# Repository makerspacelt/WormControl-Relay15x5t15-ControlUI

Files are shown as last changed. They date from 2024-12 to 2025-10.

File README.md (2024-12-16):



---
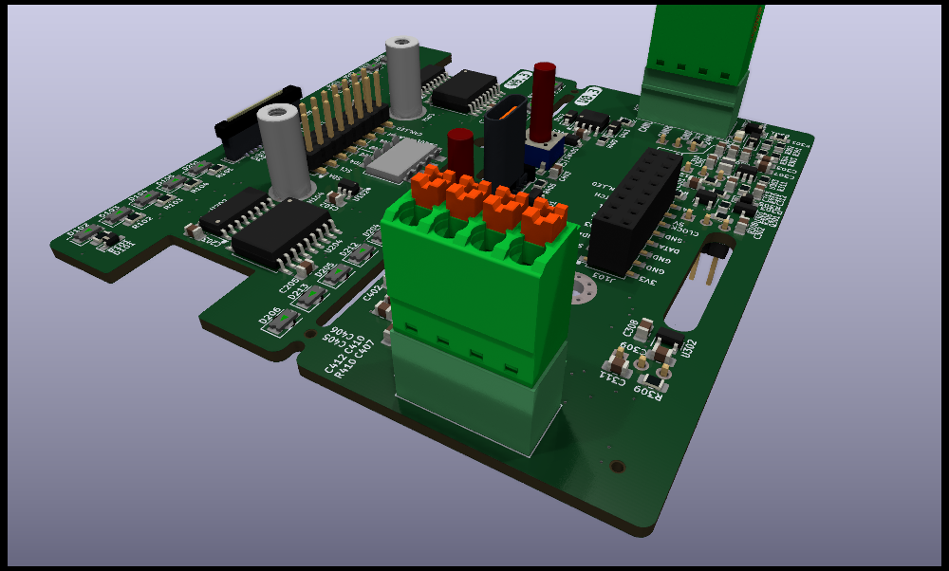
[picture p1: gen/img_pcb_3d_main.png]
PCB 3d main


WormControl Relay Control and User Interface boards

NOTE: This is only a prototype now, so things might not work and everything might change 

Basic target features:

* Compatibility with esphome and Home Assistant

Dev NOTE: before commit, run `./kibot.sh` to regenerate documentation, bom, gerbers and other assets.

* [schematics.pdf](gen/schematics.pdf)
* [pcb.pdf with dimensions](gen/pcb.pdf)
* [ibom.html](gen/single/ibom.html)

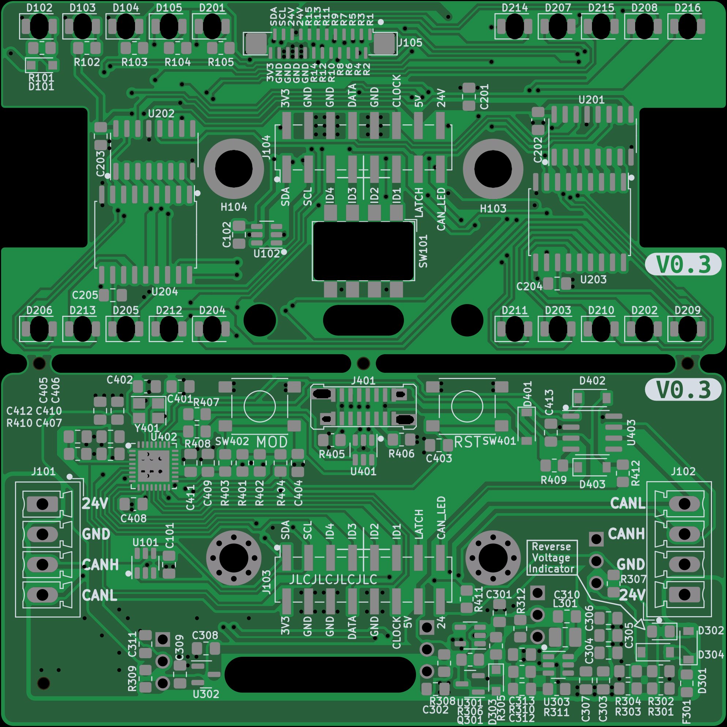
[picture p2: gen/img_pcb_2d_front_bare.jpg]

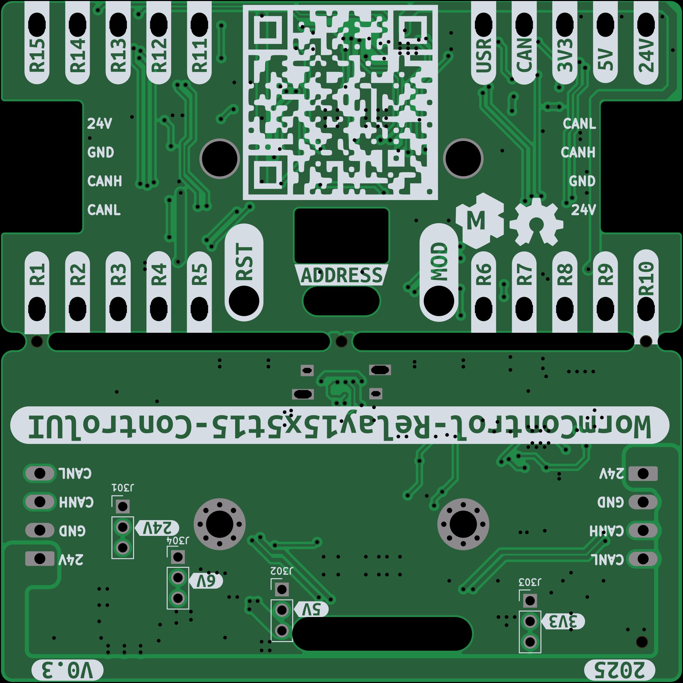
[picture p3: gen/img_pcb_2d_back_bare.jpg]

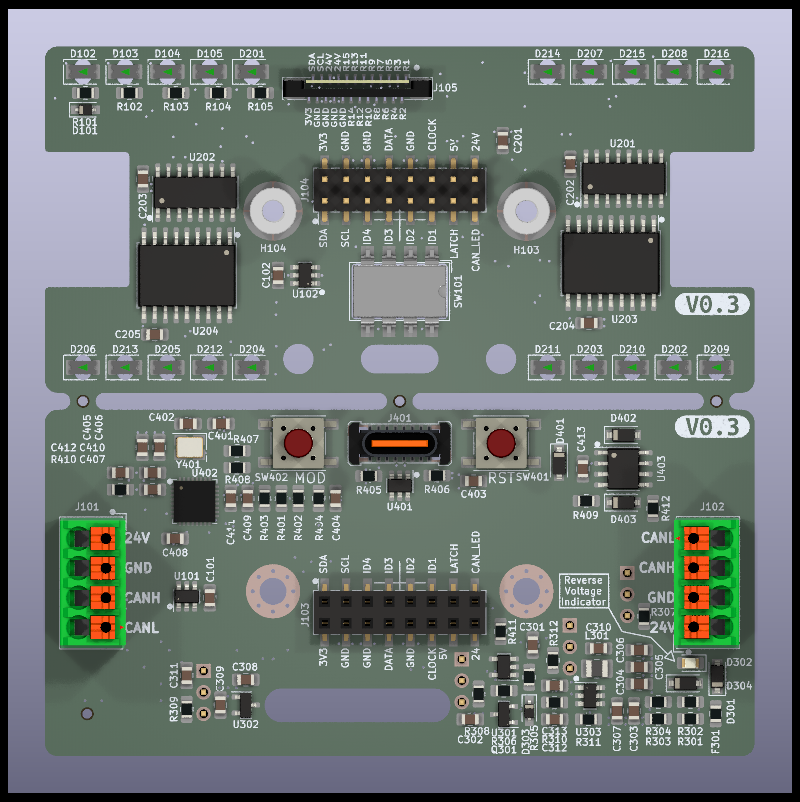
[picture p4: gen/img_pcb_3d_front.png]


---

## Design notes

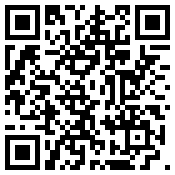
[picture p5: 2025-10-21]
gen/qr_link.png

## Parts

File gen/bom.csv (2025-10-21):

Row | Description | Part | References | Value | Footprint | Quantity Per PCB | Status | Datasheet | lcsc# | jlc-part-type | alt#
1 | Heatsink | Heatsink | BOM101,BOM102 | 1x4 screw plug |  | 2 |  | https://www.lcsc.com/datasheet/lcsc_datasheet_2309070925_DEGSON-15EDGKN-3-5-04P-14-00A-H_C7603442.pdf | C7603442 | E
2 | Unpolarized capacitor | C | C401,C402 | 10p | C_0805_2012Metric_Pad1.18x1.45mm_HandSolder | 2 |  | https://www.lcsc.com/datasheet/lcsc_datasheet_2304140030_Samsung-Electro-Mechanics-CL10C100JB8NNNC_C1634.pdf | C1634 | B
3 | Unpolarized capacitor | C | C312 | 100p | C_0805_2012Metric_Pad1.18x1.45mm_HandSolder | 1 |  | https://www.lcsc.com/datasheet/lcsc_datasheet_2304140030_Samsung-Electro-Mechanics-CL21C101JBANNNC_C1790.pdf | C1790 | B
4 | Unpolarized capacitor | C | C101,C102,C202,C203,C307,C310,C403,C404,C407,C408,C409,C410,C411,C412,C413 | 100n | C_0805_2012Metric_Pad1.18x1.45mm_HandSolder | 15 |  | https://www.lcsc.com/datasheet/lcsc_datasheet_2304140030_Samsung-Electro-Mechanics-CL21B104KCFNNNE_C28233.pdf | C28233 | B
5 | Unpolarized capacitor | C | C406 | 1u | C_0805_2012Metric_Pad1.18x1.45mm_HandSolder | 1 |  | https://www.lcsc.com/datasheet/lcsc_datasheet_2304140030_Samsung-Electro-Mechanics-CL21B105KBFNNNE_C28323.pdf | C28323 | B
6 | Unpolarized capacitor | C | C204,C205,C301,C303,C304,C305,C306,C313 | 10u/50v | C_0805_2012Metric_Pad1.18x1.45mm_HandSolder | 8 |  | https://www.lcsc.com/datasheet/lcsc_datasheet_2411041759_Murata-Electronics-GRM21BR61H106KE43L_C440198.pdf | C440198 | B
7 | Unpolarized capacitor | C | C201,C302,C308,C405 | 22u/25v | C_0805_2012Metric_Pad1.18x1.45mm_HandSolder | 4 |  | https://www.lcsc.com/datasheet/lcsc_datasheet_2304140030_Samsung-Electro-Mechanics-CL21A226MAQNNNE_C45783.pdf | C45783 | B
8 | Unpolarized capacitor | C | C309,C311 | 47u/6V3 | C_0805_2012Metric_Pad1.18x1.45mm_HandSolder | 2 |  | https://www.lcsc.com/datasheet/lcsc_datasheet_2304140030_Samsung-Electro-Mechanics-CL21A226MAQNNNE_C45783.pdf | C16780 | B
9 | Zener diode | D_Zener | D101,D303 | 6V8 | D_SOD-323_HandSoldering | 2 |  | https://www.lcsc.com/datasheet/C123062.pdf | C123062 | E
10 | Schottky diode | D_Schottky | D301,D304,D401,D402,D403 | B5819W | D_SOD-123 | 5 |  | https://www.lcsc.com/datasheet/lcsc_datasheet_2304140030_Jiangsu-Changjing-Electronics-Technology-Co---Ltd--B5819W-SL_C8598.pdf | C8598 | B
11 | Light emitting diode | LED | D302 | BLUE | LED_0805_2012Metric_Pad1.15x1.40mm_HandSolder | 1 |  | https://jlcpcb.com/api/file/downloadByFileSystemAccessId/8550724011370958848 | C2297 | B
12 | Light emitting diode | LED | D102,D103,D104,D105,D201,D202,D203,D204,D205,D206,D207,D208,D209,D210,D211,D212,D213,D214,D215,D216 | RED | LED_1206_3216Metric_ReverseMount | 20 |  | https://www.lcsc.com/datasheet/lcsc_datasheet_2302091130_TOGIALED-TJ-S3216SWETNPLC2R-A5_C5356080.pdf | C5356080 | E
13 | Resettable fuse, polymeric positive temperature coefficient | Polyfuse | F301 | 250mA | Fuse_0805_2012Metric_Pad1.15x1.40mm_HandSolder | 1 |  | https://wmsc.lcsc.com/wmsc/upload/file/pdf/v2/lcsc/2404081622_BHFUSE-BSMD0805-025-33V_C22378353.pdf | C22378353 | E
14 | Generic connector, single row, 01x03, script generated (kicad-library-utils/schlib/autogen/connector/) | Conn_01x03 | J301,J302,J303,J304 | 24V | PinHeader_1x03_P2.54mm_Vertical | 4 |  | ~ |  | -
15 | Generic screw terminal, single row, 01x04, script generated (kicad-library-utils/schlib/autogen/connector/) | Screw_Terminal_01x04 | J101,J102 | BUS | PhoenixContact_MCV_1,5_4-G-3.5_1x04_P3.50mm_Vertical | 2 |  | https://www.lcsc.com/datasheet/lcsc_datasheet_2304140030_Ningbo-Xinlaiya-Elec--XY2500V-F-3-5-4P_C880556.pdf | C880556 | E
16 | Generic connector, single row, 01x16, script generated (kicad-library-utils/schlib/autogen/connector/) | Conn_01x16 | J103 | Back | PinSocket_2x08_P2.54mm_Vertical_SMD | 1 |  | https://wmsc.lcsc.com/wmsc/upload/file/pdf/v2/lcsc/2306091018_HCTL-PM254-2-08-S-8-5_C3975153.pdf | C3975153 | E
17 | Generic connectable mounting pin connector, single row, 01x24, script generated (kicad-library-utils/schlib/autogen/connector/) | Conn_01x24_MountingPin | J105 | FFC | AFC11-S24ICC-00 | 1 |  | https://www.lcsc.com/datasheet/lcsc_datasheet_2212161930_JUSHUO-AFC11-S24ICC-00_C11075.pdf | C11075 | E
18 | Generic connector, single row, 01x16, script generated (kicad-library-utils/schlib/autogen/connector/) | Conn_01x16 | J104 | Front | PinHeader_2x08_P2.54mm_Vertical_SMD | 1 |  | https://wmsc.lcsc.com/wmsc/upload/file/pdf/v2/lcsc/2209141730_DEALON-DZ254S-22-16-75_C5160782.pdf | C5160782 | E
19 | USB 2.0-only Type-C Receptacle connector | USB_C_Receptacle_USB2.0 | J401 | USB_C_Receptacle_USB2.0 | USB_C_Receptacle_G-Switch_GT-USB-7082G | 1 |  | https://www.lcsc.com/datasheet/lcsc_datasheet_2405271642_G-Switch-GT-USB-7082G_C22383836.pdf | C22383836 | E
20 | Inductor | L | L301 | 3.3uH | L_1008_2520Metric_Pad1.43x2.20mm_HandSolder | 1 |  | https://www.lcsc.com/datasheet/C5832373.pdf | C5832373 | E
21 | NPN transistor, base/emitter/collector | Q_NPN_BEC | Q301 | MMBT3904 | SOT-23 | 1 |  | https://www.lcsc.com/datasheet/C20526.pdf | C20526 | B
22 | Resistor | R | R307,R308,R309,R312 | 0R1 | R_0805_2012Metric_Pad1.20x1.40mm_HandSolder | 4 |  | https://www.lcsc.com/datasheet/lcsc_datasheet_2304140030_UNI-ROYAL-Uniroyal-Elec-0805W8F100LT5E_C127687.pdf | C127687 | E
23 | Resistor | R | R407,R408 | 22R | R_0805_2012Metric_Pad1.20x1.40mm_HandSolder | 2 |  | ~ | C17561 | B
24 | Resistor | R | R103,R104,R105,R301,R302,R303,R304,R401,R402,R403,R404,R405,R406,R409,R410,R412 | 4k7 | R_0805_2012Metric_Pad1.20x1.40mm_HandSolder | 16 |  | ~ | C17673 | B
25 | Resistor | R | R102,R305,R306 | 10k | R_0805_2012Metric_Pad1.20x1.40mm_HandSolder | 3 |  | ~ | C17414 | B
26 | Resistor | R | R311 | 22k | R_0805_2012Metric_Pad1.20x1.40mm_HandSolder | 1 |  | ~ | C17560 | B
27 | Resistor | R | R101 | 47k | R_0805_2012Metric_Pad1.20x1.40mm_HandSolder | 1 |  | ~ | C17713 | B
28 | Resistor | R | R411 | 150k | R_0805_2012Metric_Pad1.20x1.40mm_HandSolder | 1 |  | ~ | C17470 | B
29 | Resistor | R | R310 | 200k | R_0805_2012Metric_Pad1.20x1.40mm_HandSolder | 1 |  | ~ | C17539 | B
30 | Push button switch, generic, two pins | SW_Push | SW401,SW402 | 15mm | SW_SPST_15 | 2 |  | https://www.lcsc.com/datasheet/lcsc_datasheet_2110120830_XKB-Connection-TS-1102S-C-V-B_C2885154.pdf | C2885154 | E
31 | 4x DIP Switch, Single Pole Single Throw (SPST) switch, small symbol | SW_DIP_x04 | SW101 | SW_DIP_x04 | SW_DIP_SPSTx04_Slide_6.2x11.16mm_P2.54mm | 1 |  | https://www.lcsc.com/datasheet/lcsc_datasheet_2304140030_KAIFENG-KF1027B-04P-G00-DFT-01B_C976366.pdf | C976366 | E
32 | 8-bit serial in/out Shift Register 3-State Outputs | 74HC595 | U201,U202 | 74HC595 | SOIC-16_3.9x9.9mm_P1.27mm | 2 |  | https://www.lcsc.com/datasheet/lcsc_datasheet_2407241044_Nexperia-74HC595D-118_C5947.pdf | C5947 | B
33 | Digital Temperature Sensor with I2C/SMBus Interface, +/-2° C, one-shot conversion, alert, SOT-23-6 | TMP101 | U101,U102 | GX101 | SOT-23-6 | 2 |  | https://www.lcsc.com/datasheet/lcsc_datasheet_2409280202_GXCAS-GX101S_C5441728.pdf | C5441728 | E
34 | 300mA Low Dropout Voltage Regulator, Fixed Output 3.3V, SOT-23 | APE8865N-33-HF-3 | U302 | JTD6206-3.3V | SOT-23 | 1 |  | https://www.lcsc.com/datasheet/C42443428.pdf | C5446 | B | C42443428
35 | 300mA Low Dropout Voltage Regulator, Fixed Output 0.9V, SOT-23-5 | TLV71209_SOT23-5 | U301 | LW6550A23E | SOT-23-5 | 1 |  | https://www.lcsc.com/datasheet/C20754712.pdf | C20754712 | E
36 | 1.2 A Simple Buck Regulator, 3-26V input, 1.5Mhz | AOZ1280CI | U303 | ME3121AM6G | SOT-23-6 | 1 |  | https://m.huazhoucn.com/upFiles/common/2022/12/ME3121_Series_E1.0.pdf | C2932938 | E
37 | Darlington Transistor Arrays, SOIC18/DIP18 | ULN2803A | U203,U204 | ULN2803A | SOIC-18W_7.5x11.6mm_P1.27mm | 2 |  | https://www.lcsc.com/datasheet/lcsc_datasheet_2311091738_UMW-Youtai-Semiconductor-Co---Ltd--ULN2803A_C845537.pdf | C845537 | E
38 | Very low capacitance ESD protection diode, 2 data-line, SOT-23-6 | USBLC6-2SC6 | U401 | USBLC6-2SC6 | SOT-23-6 | 1 |  | https://www.lcsc.com/datasheet/lcsc_datasheet_2311091738_UMW-Youtai-Semiconductor-Co---Ltd--USBLC6-2SC6_C2687116.pdf | C2687116 | E
39 | High-Speed CAN Transceiver, standby mode, split pin, SOIC-8 | TJA1042T | U403 | XL1050 | SOIC-8_3.9x4.9mm_P1.27mm | 1 |  | https://www.lcsc.com/datasheet/lcsc_datasheet_2309141025_XINLUDA-XL1050_C609746.pdf | C609746 | E
40 | esp32-C3FH4X 4MB flash QFN32-1EP 5x5mm EP3.7x3.7mm | esp32-C3FH4X | U402 | esp32-C3FH4X | QFN-32-1EP_5x5mm_P0.5mm_EP3.65x3.65mm | 1 |  | https://www.espressif.com/sites/default/files/documentation/esp32-c3_datasheet_en.pdf | C2858491 | E
41 | Four pin crystal, GND on pins 2 and 4 | Crystal_GND24 | Y401 | 40MHz | Crystal_SMD_3225-4Pin_3.2x2.5mm | 1 |  | https://wmsc.lcsc.com/wmsc/upload/file/pdf/v2/lcsc/2311101855_SST-SCGYS40X00000YLXWPM_C19191260.pdf | C19191260 | E

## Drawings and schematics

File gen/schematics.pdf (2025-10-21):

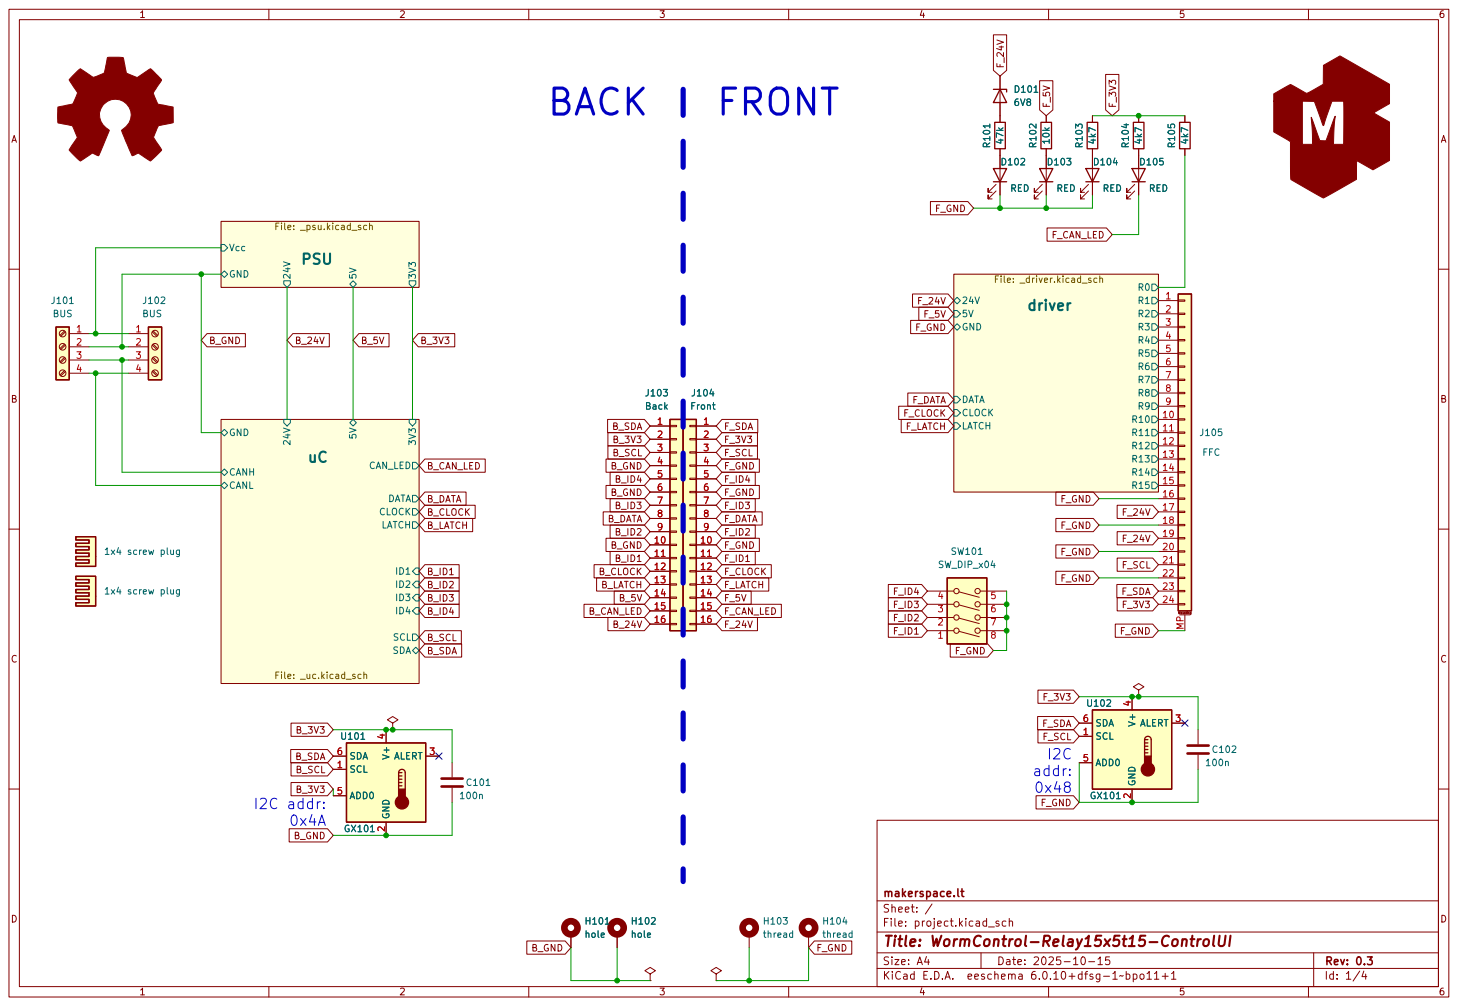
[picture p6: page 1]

File: project.kicad_sch Sheet: / makerspace.lt

Id: 1/4 Title: WormControl-Relay15x5t15-ControlUI

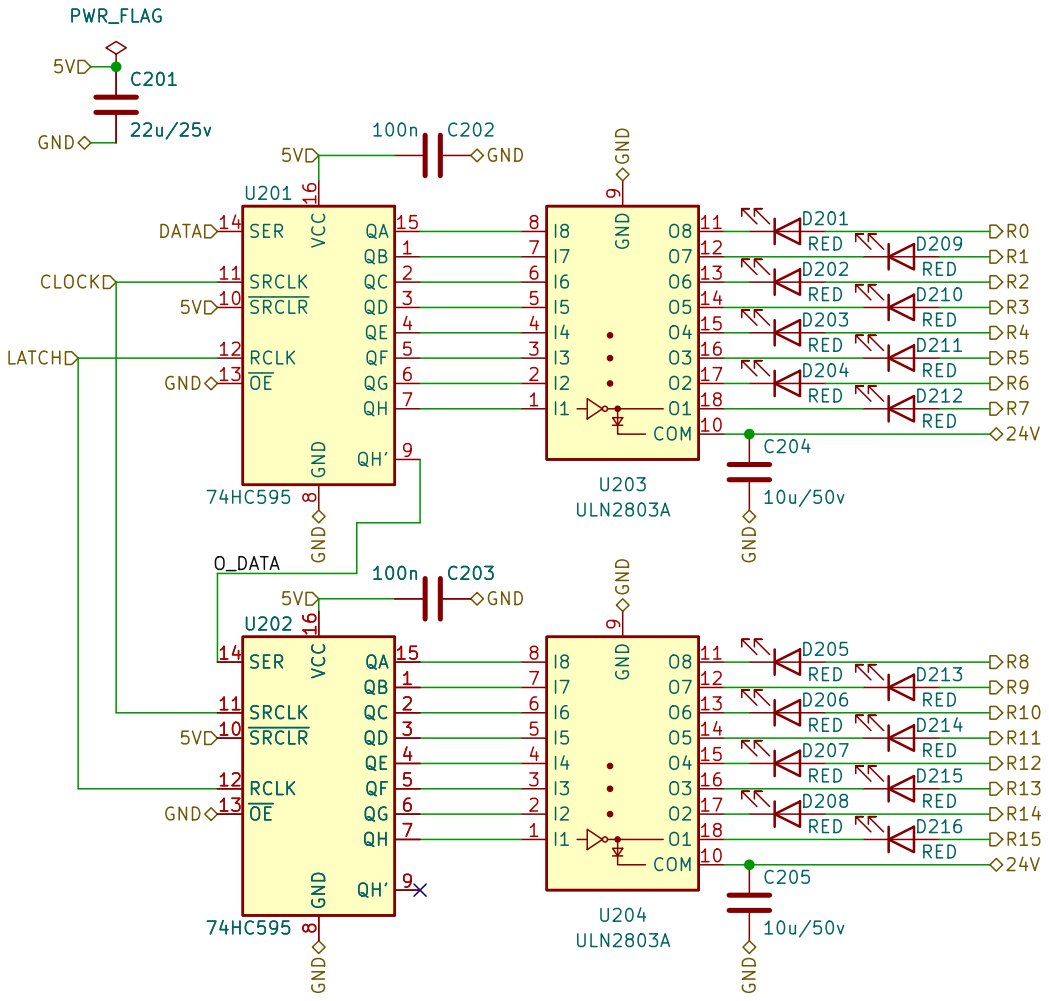
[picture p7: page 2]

Id: 2/4 Title: WormControl-Relay15x5t15-ControlUI

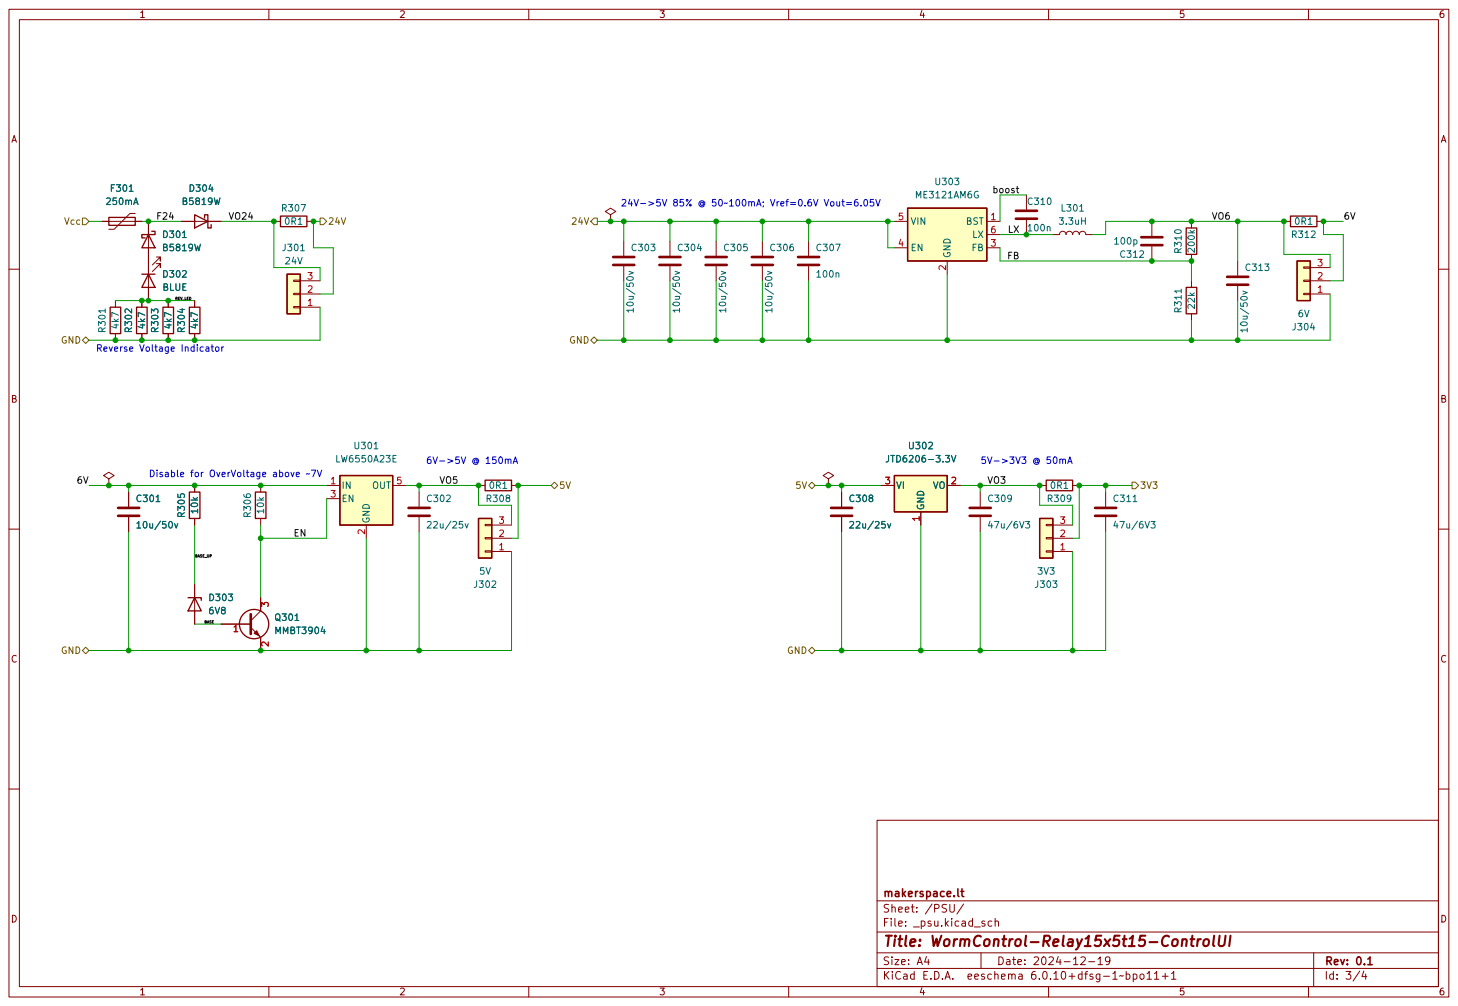
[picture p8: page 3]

boost Disable for OverVoltage above ~7V

File: _psu.kicad_sch Sheet: /PSU/ makerspace.lt R308

Id: 3/4 Title: WormControl-Relay15x5t15-ControlUI

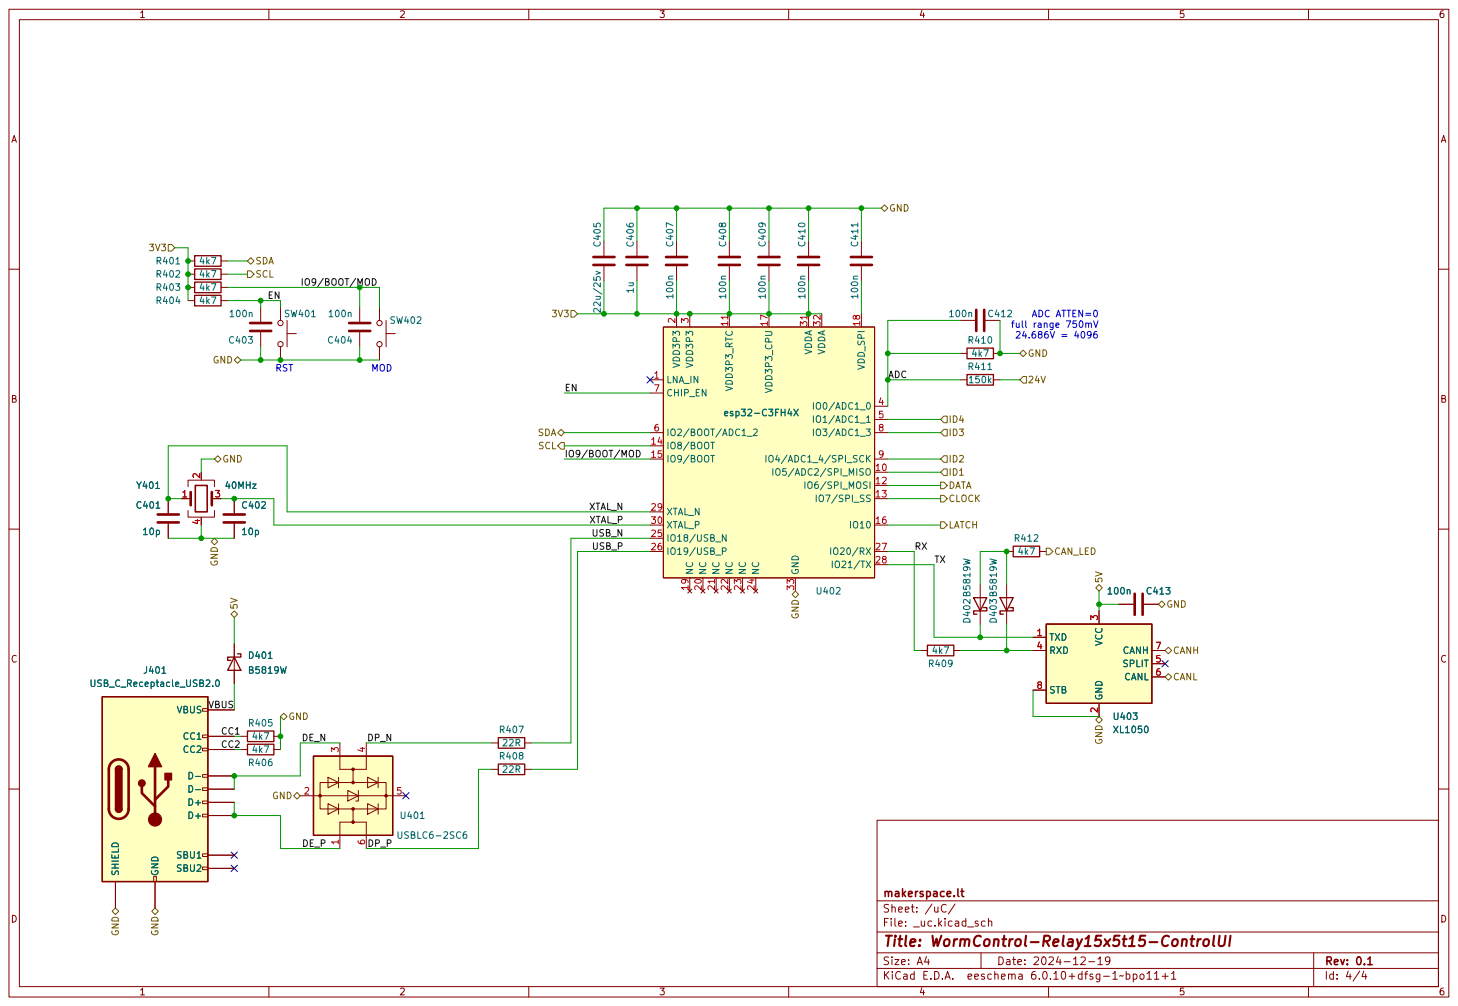
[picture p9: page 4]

3 RXD 4 SPLIT 5 CANL 6 CANH 7 STB 8 U403 XL1050 SW401 C404

3 RXD 4 SPLIT 5 CANL 6 CANH 7 STB 8

File: _uc.kicad_sch Sheet: /uC/ makerspace.lt R407

Id: 4/4 Title: WormControl-Relay15x5t15-ControlUI

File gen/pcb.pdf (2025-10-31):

84.0 mm

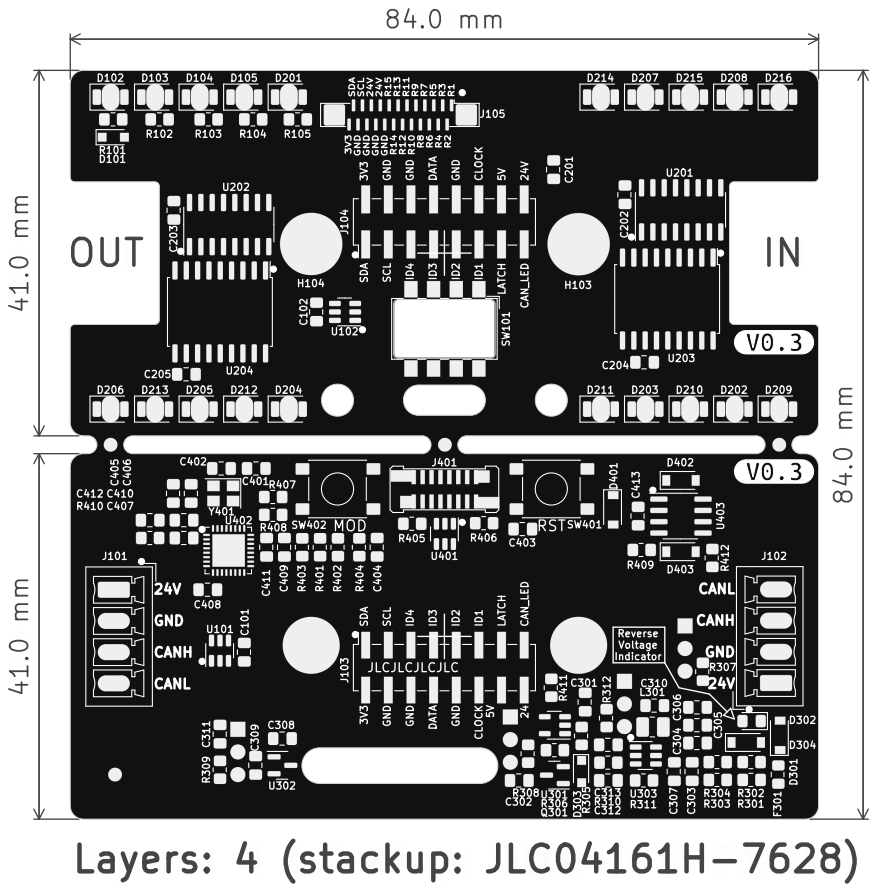
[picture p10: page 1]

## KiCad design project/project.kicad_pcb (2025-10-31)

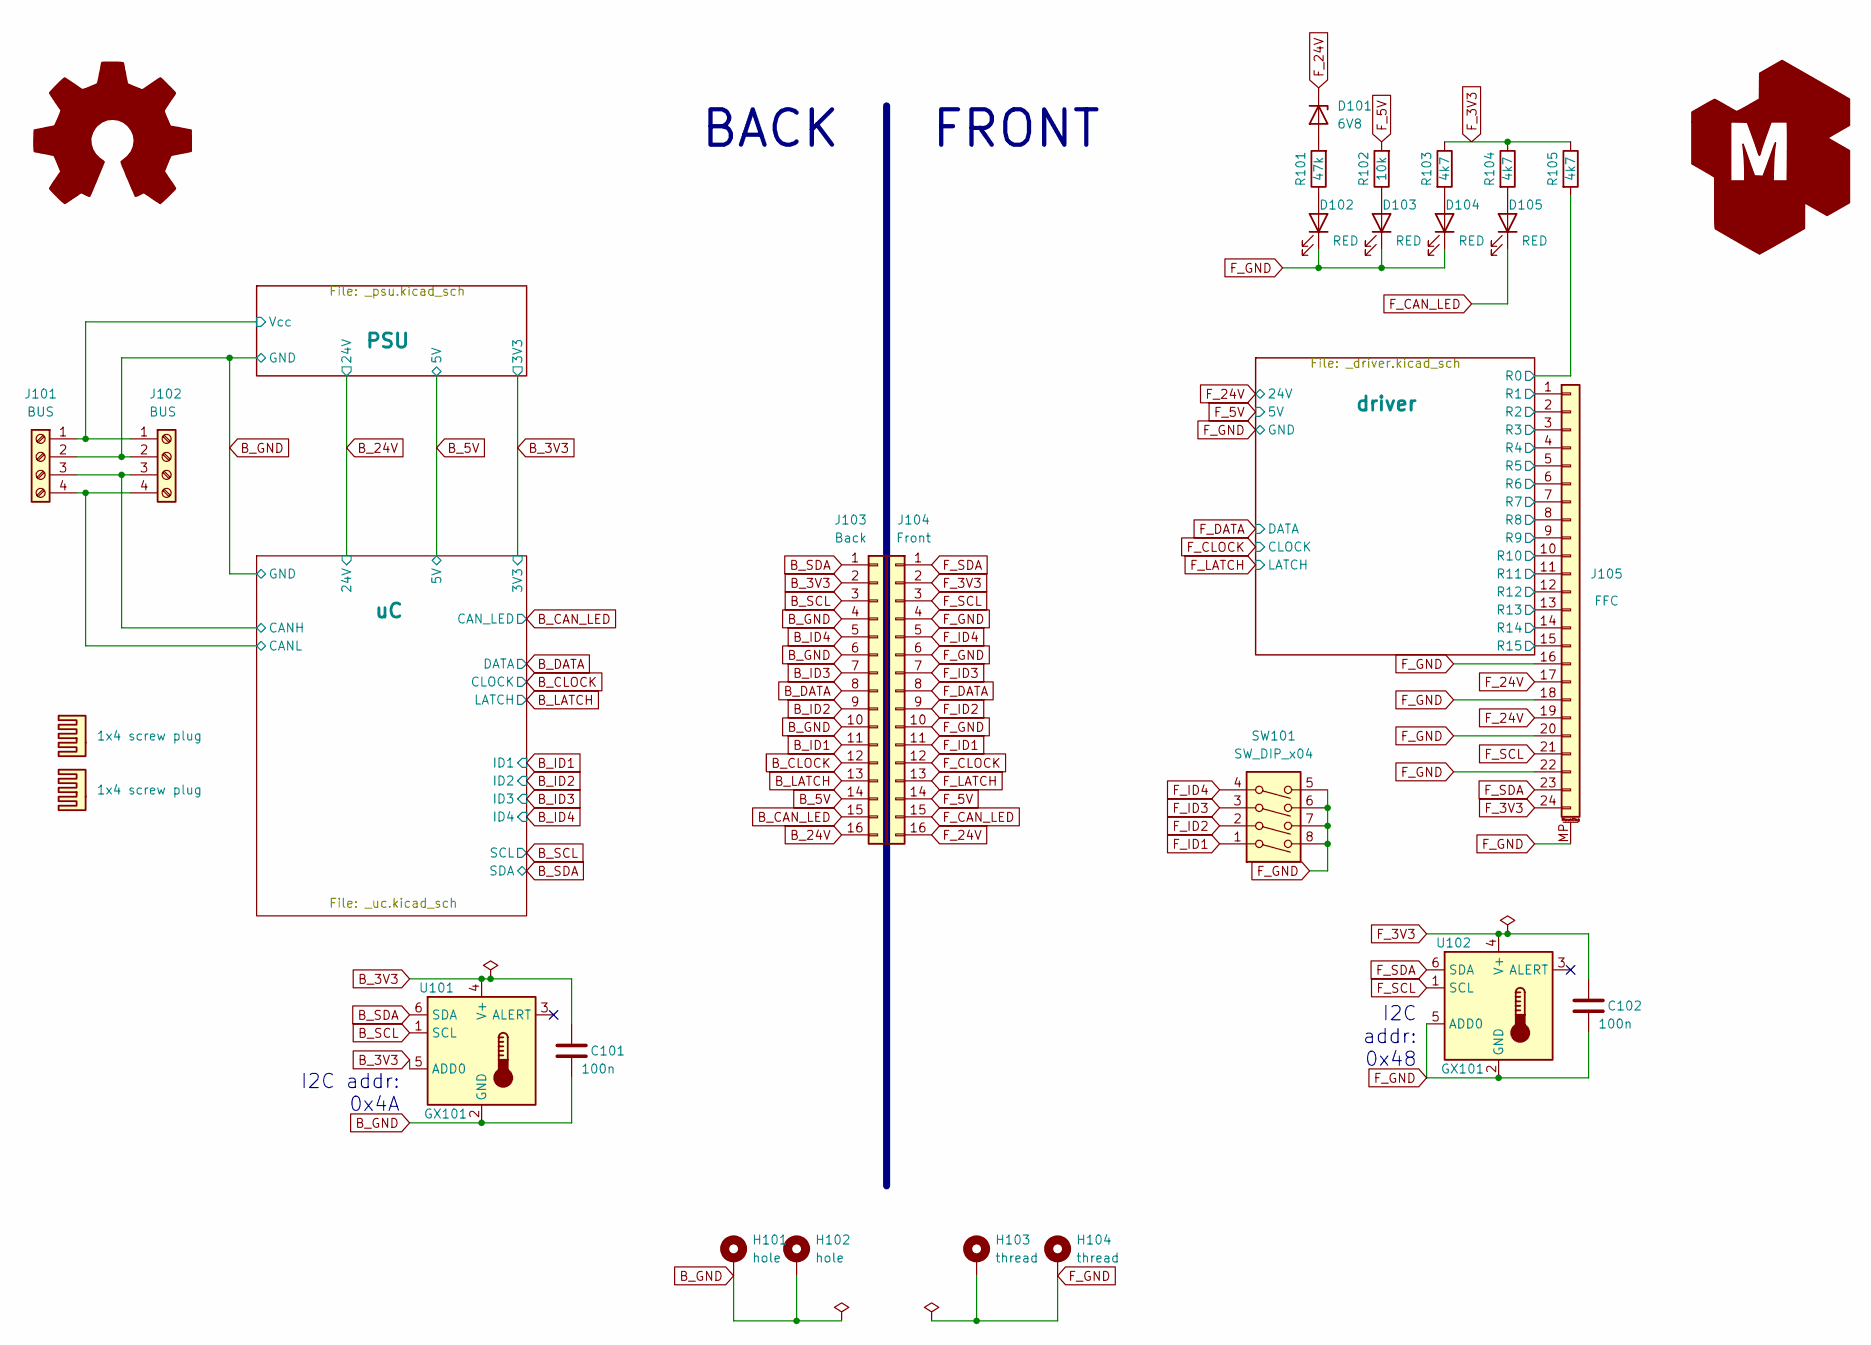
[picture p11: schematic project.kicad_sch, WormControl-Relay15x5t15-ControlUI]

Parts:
BOM101, BOM102: 1x4 screw plug; jlc-part-type E
C101, C102: 100n; C_0805_2012Metric_Pad1.18x1.45mm_HandSolder; jlc-part-type B
D101: 6V8; D_SOD-323_HandSoldering; jlc-part-type E
D102, D103, D104, D105: RED; LED_1206_3216Metric_ReverseMount; jlc-part-type E
G101: Logo_Open_Hardware_Large; OSHW-Symbol_6.7x6mm_SilkScreen
G102: LOGO_KMS; logo_kms_small_silkscreen
H101, H102: hole; MountingHole_3.2mm_M3_Pad_Via
H103, H104: thread; post_m3x12.5mm; lcsc# C30182781
J101, J102: BUS; PhoenixContact_MCV_1,5_4-G-3.5_1x04_P3.50mm_Vertical; jlc-part-type E
J103: Back; PinSocket_2x08_P2.54mm_Vertical_SMD; lcsc# C3975153
J104: Front; PinHeader_2x08_P2.54mm_Vertical_SMD; lcsc# C5160782
J105: FFC; AFC11-S24ICC-00; jlc-part-type E
R101: 47k; R_0805_2012Metric_Pad1.20x1.40mm_HandSolder; jlc-part-type B
R102: 10k; R_0805_2012Metric_Pad1.20x1.40mm_HandSolder; jlc-part-type B
R103, R104, R105: 4k7; R_0805_2012Metric_Pad1.20x1.40mm_HandSolder; jlc-part-type B
SW101: SW_DIP_x04; SW_DIP_SPSTx04_Slide_6.2x11.16mm_P2.54mm; lcsc# C976366
U101, U102: GX101; SOT-23-6; jlc-part-type E

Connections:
/PSU/Vcc: J101.1, J102.1; also elsewhere on the board
/driver/R0: R105.2; also elsewhere on the board
/driver/R1: J105.1; also elsewhere on the board
/driver/R2: J105.2; also elsewhere on the board
/driver/R3: J105.3; also elsewhere on the board
/driver/R4: J105.4; also elsewhere on the board
/driver/R5: J105.5; also elsewhere on the board
/driver/R6: J105.6; also elsewhere on the board
/driver/R7: J105.7; also elsewhere on the board
/driver/R8: J105.8; also elsewhere on the board
/driver/R9: J105.9; also elsewhere on the board
/driver/R10: J105.10; also elsewhere on the board
/driver/R11: J105.11; also elsewhere on the board
/driver/R12: J105.12; also elsewhere on the board
/driver/R13: J105.13; also elsewhere on the board
/driver/R14: J105.14; also elsewhere on the board
/driver/R15: J105.15; also elsewhere on the board
/uC/CANH: J101.3, J102.3; also elsewhere on the board
/uC/CANL: J101.4, J102.4; also elsewhere on the board
B_3V3: C101.1, J103.2, U101.4 (V+), U101.5 (ADD0); also elsewhere on the board
B_5V: J103.14; also elsewhere on the board
B_24V: J103.16; also elsewhere on the board
B_CAN_LED: J103.15; also elsewhere on the board
B_CLOCK: J103.12; also elsewhere on the board
B_DATA: J103.8; also elsewhere on the board
B_GND: C101.2, H101.1, H102.1, J101.2, J102.2, J103.4, J103.6, J103.10, U101.2 (GND); also elsewhere on the board
B_ID1: J103.11; also elsewhere on the board
B_ID2: J103.9; also elsewhere on the board
B_ID3: J103.7; also elsewhere on the board
B_ID4: J103.5; also elsewhere on the board
B_LATCH: J103.13; also elsewhere on the board
B_SCL: J103.3, U101.1 (SCL); also elsewhere on the board
B_SDA: J103.1, U101.6 (SDA); also elsewhere on the board
F_3V3: C102.1, J104.2, J105.24, R103.1, R104.1, R105.1, U102.4 (V+)
F_5V: J104.14, R102.2; also elsewhere on the board
F_24V: D101.1 (K), J104.16, J105.17, J105.19; also elsewhere on the board
F_CAN_LED: D105.1 (K), J104.15
F_CLOCK: J104.12; also elsewhere on the board
F_DATA: J104.8; also elsewhere on the board
F_GND: C102.2, D102.1 (K), D103.1 (K), D104.1 (K), H103.1, H104.1, J104.4, J104.6, J104.10, J105.16, J105.18, J105.20, J105.22, J105.MP (MountPin), SW101.5, SW101.6, SW101.7, SW101.8, U102.2 (GND), U102.5 (ADD0); also elsewhere on the board
F_ID1: J104.11, SW101.1
F_ID2: J104.9, SW101.2
F_ID3: J104.7, SW101.3
F_ID4: J104.5, SW101.4
F_LATCH: J104.13; also elsewhere on the board
F_SCL: J104.3, J105.21, U102.1 (SCL)
F_SDA: J104.1, J105.23, U102.6 (SDA)
unnamed: D101.2 (A), R101.2
unnamed: D102.2 (A), R101.1
unnamed: D103.2 (A), R102.1
unnamed: D104.2 (A), R103.2
unnamed: D105.2 (A), R104.2

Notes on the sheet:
I2C addr: 0x48
FRONT
I2C addr: 0x4A
BACK

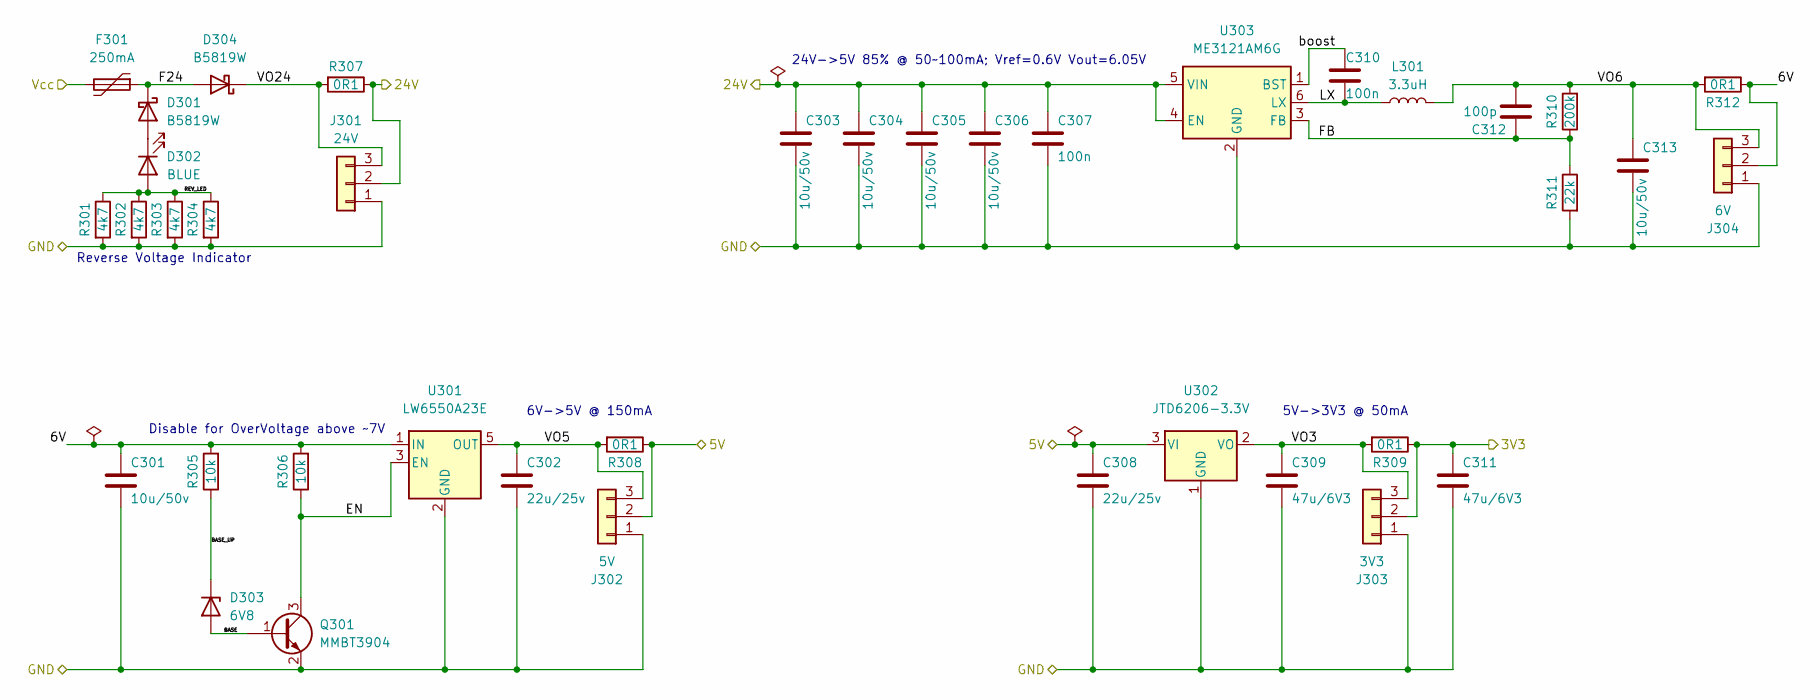
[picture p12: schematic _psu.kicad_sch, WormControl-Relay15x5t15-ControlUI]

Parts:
C301, C303, C304, C305, C306, C313: 10u/50v; C_0805_2012Metric_Pad1.18x1.45mm_HandSolder; jlc-part-type B
C302, C308: 22u/25v; C_0805_2012Metric_Pad1.18x1.45mm_HandSolder; jlc-part-type B
C307, C310: 100n; C_0805_2012Metric_Pad1.18x1.45mm_HandSolder; jlc-part-type B
C309, C311: 47u/6V3; C_0805_2012Metric_Pad1.18x1.45mm_HandSolder; jlc-part-type B
C312: 100p; C_0805_2012Metric_Pad1.18x1.45mm_HandSolder; jlc-part-type B
D301, D304: B5819W; D_SOD-123; jlc-part-type B
D302: BLUE; LED_0805_2012Metric_Pad1.15x1.40mm_HandSolder; jlc-part-type B
D303: 6V8; D_SOD-323_HandSoldering; jlc-part-type E
F301: 250mA; Fuse_0805_2012Metric_Pad1.15x1.40mm_HandSolder; lcsc# C22378353
J301: 24V; PinHeader_1x03_P2.54mm_Vertical
J302: 5V; PinHeader_1x03_P2.54mm_Vertical
J303: 3V3; PinHeader_1x03_P2.54mm_Vertical
J304: 6V; PinHeader_1x03_P2.54mm_Vertical
L301: 3.3uH; L_1008_2520Metric_Pad1.43x2.20mm_HandSolder; jlc-part-type E
Q301: MMBT3904; SOT-23; jlc-part-type B
R301, R302, R303, R304: 4k7; R_0805_2012Metric_Pad1.20x1.40mm_HandSolder; jlc-part-type B
R305, R306: 10k; R_0805_2012Metric_Pad1.20x1.40mm_HandSolder; jlc-part-type B
R307, R308, R309, R312: 0R1; R_0805_2012Metric_Pad1.20x1.40mm_HandSolder; jlc-part-type E
R310: 200k; R_0805_2012Metric_Pad1.20x1.40mm_HandSolder; jlc-part-type B
R311: 22k; R_0805_2012Metric_Pad1.20x1.40mm_HandSolder; jlc-part-type B
U301: LW6550A23E; SOT-23-5; jlc-part-type E
U302: JTD6206-3.3V; SOT-23; jlc-part-type B
U303: ME3121AM6G; SOT-23-6; jlc-part-type E

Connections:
/PSU/6V: C301.1, J304.2, R305.2, R306.2, R312.1, U301.1 (IN)
/PSU/BASE: D303.2 (A), Q301.1 (B)
/PSU/BASE_UP: D303.1 (K), R305.1
/PSU/EN: Q301.3 (C), R306.1, U301.3 (EN)
/PSU/F24: D301.1 (K), D304.2 (A), F301.1
/PSU/FB: C312.1, R310.1, R311.1, U303.3 (FB)
/PSU/LX: C310.2, L301.1, U303.6 (LX)
/PSU/REV_LED: D302.2 (A), R301.1, R302.1, R303.1, R304.1
/PSU/VO3: C309.1, J303.3, R309.2, U302.2 (VO)
/PSU/VO5: C302.1, J302.3, R308.2, U301.5 (OUT)
/PSU/VO6: C312.2, C313.1, J304.3, L301.2, R310.2, R312.2
/PSU/VO24: D304.1 (K), J301.3, R307.2
/PSU/Vcc: F301.2; also elsewhere on the board
/PSU/boost: C310.1, U303.1 (BST)
B_3V3: C311.1, J303.2, R309.1; also elsewhere on the board
B_5V: C308.1, J302.2, R308.1, U302.3 (VI); also elsewhere on the board
B_24V: C303.1, C304.1, C305.1, C306.1, C307.1, J301.2, R307.1, U303.4 (EN), U303.5 (VIN); also elsewhere on the board
B_GND: C301.2, C302.2, C303.2, C304.2, C305.2, C306.2, C307.2, C308.2, C309.2, C311.2, C313.2, J301.1, J302.1, J303.1, J304.1, Q301.2 (E), R301.2, R302.2, R303.2, R304.2, R311.2, U301.2 (GND), U302.1 (GND), U303.2 (GND); also elsewhere on the board
unnamed: D301.2 (A), D302.1 (K)

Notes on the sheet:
24V->5V 85% @ 50~100mA; Vref=0.6V Vout=6.05V
5V->3V3 @ 50mA
Reverse Voltage Indicator
6V->5V @ 150mA
Disable for OverVoltage above ~7V

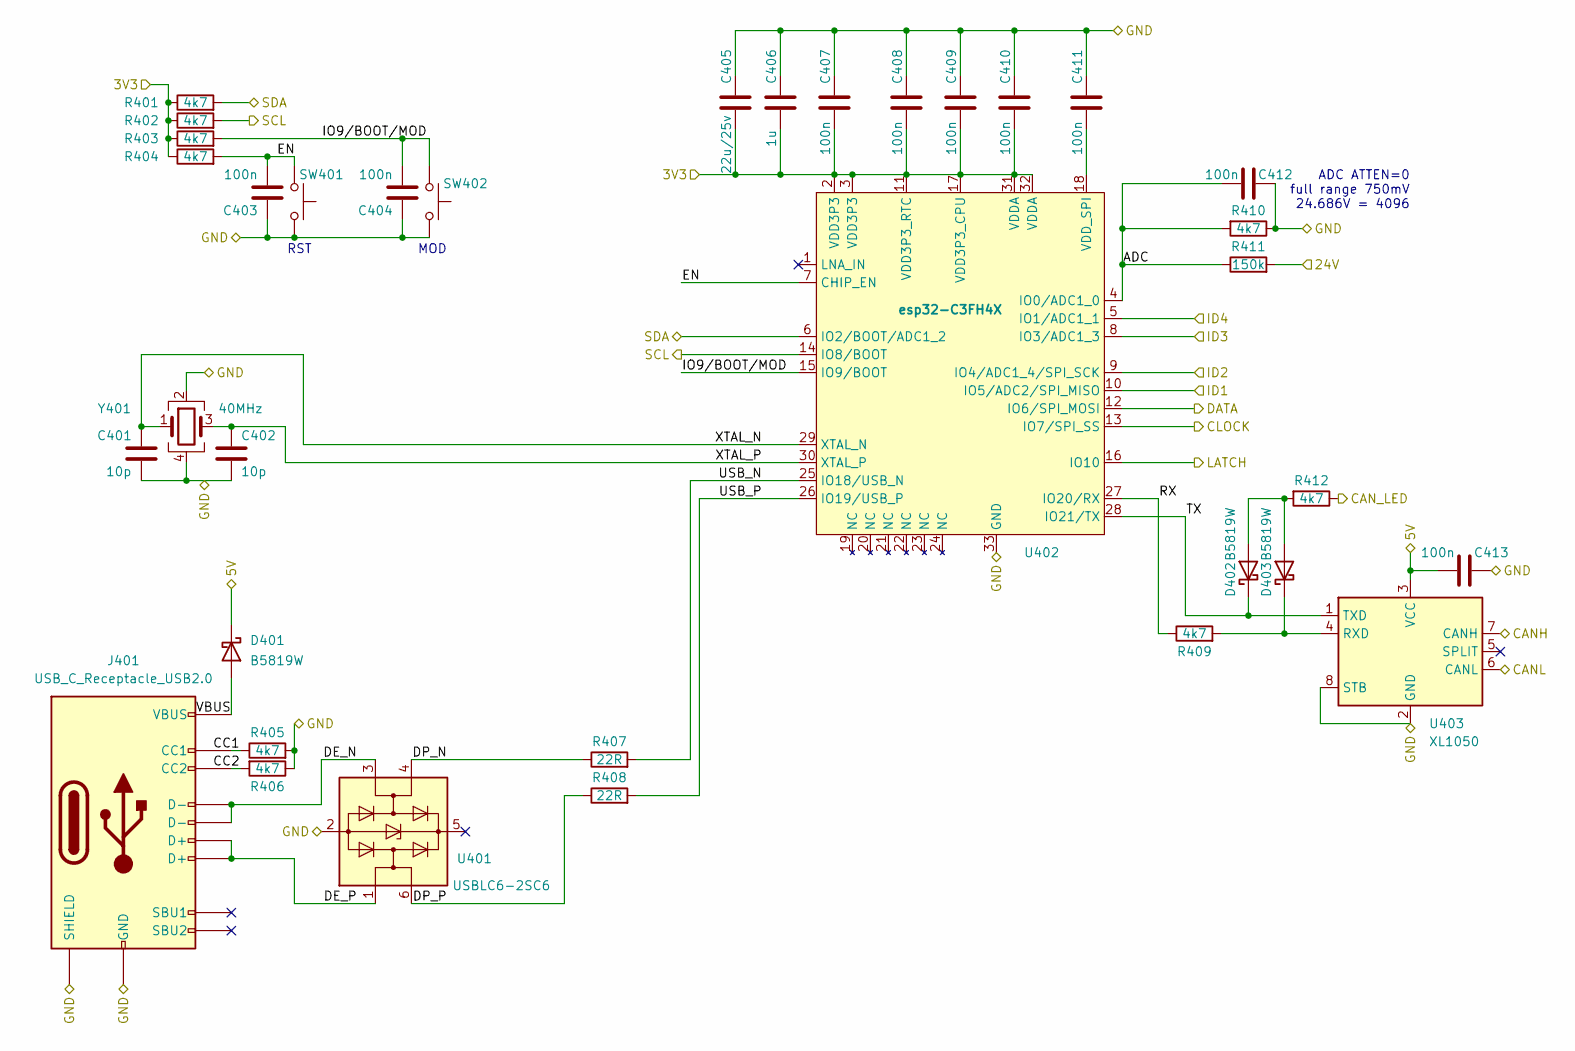
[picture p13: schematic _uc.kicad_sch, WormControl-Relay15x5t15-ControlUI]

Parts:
C401, C402: 10p; C_0805_2012Metric_Pad1.18x1.45mm_HandSolder; jlc-part-type B
C403, C404, C407, C408, C409, C410, C411, C412, C413: 100n; C_0805_2012Metric_Pad1.18x1.45mm_HandSolder; jlc-part-type B
C405: 22u/25v; C_0805_2012Metric_Pad1.18x1.45mm_HandSolder; jlc-part-type B
C406: 1u; C_0805_2012Metric_Pad1.18x1.45mm_HandSolder; jlc-part-type B
D401, D402, D403: B5819W; D_SOD-123; jlc-part-type B
J401: USB_C_Receptacle_USB2.0; USB_C_Receptacle_G-Switch_GT-USB-7082G; jlc-part-type E
R401, R402, R403, R404, R405, R406, R409, R410, R412: 4k7; R_0805_2012Metric_Pad1.20x1.40mm_HandSolder; jlc-part-type B
R407, R408: 22R; R_0805_2012Metric_Pad1.20x1.40mm_HandSolder; jlc-part-type B
R411: 150k; R_0805_2012Metric_Pad1.20x1.40mm_HandSolder; jlc-part-type B
SW401, SW402: 15mm; SW_SPST_15; jlc-part-type E
U401: USBLC6-2SC6; SOT-23-6; jlc-part-type E
U402: esp32-C3FH4X; QFN-32-1EP_5x5mm_P0.5mm_EP3.65x3.65mm; jlc-part-type E
U403: XL1050; SOIC-8_3.9x4.9mm_P1.27mm; jlc-part-type E
Y401: 40MHz; Crystal_SMD_3225-4Pin_3.2x2.5mm; jlc-part-type E

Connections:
/uC/ADC: C412.1, R410.2, R411.1, U402.4 (IO0/ADC1_0)
/uC/CANH: U403.7 (CANH); also elsewhere on the board
/uC/CANL: U403.6 (CANL); also elsewhere on the board
/uC/CC1: J401.A5 (CC1), R405.1
/uC/CC2: J401.B5 (CC2), R406.2
/uC/DE_N: J401.A7 (D-), J401.B7 (D-), U401.3 (I/O2)
/uC/DE_P: J401.A6 (D+), J401.B6 (D+), U401.1 (I/O1)
/uC/DP_N: R407.1, U401.4 (I/O2)
/uC/DP_P: R408.1, U401.6 (I/O1)
/uC/EN: C403.2, R404.2, SW401.1, U402.7 (CHIP_EN)
/uC/IO9/BOOT/MOD: C404.2, R403.2, SW402.1, U402.15 (IO9/BOOT)
/uC/RX: R409.1, U402.27 (IO20/RX)
/uC/TX: D402.1 (K), U402.28 (IO21/TX), U403.1 (TXD)
/uC/USB_N: R407.2, U402.25 (IO18/USB_N)
/uC/USB_P: R408.2, U402.26 (IO19/USB_P)
/uC/VBUS: D401.2 (A), J401.A4 (VBUS), J401.A9 (VBUS), J401.B4 (VBUS), J401.B9 (VBUS)
/uC/XTAL_N: C401.1, U402.29 (XTAL_N), Y401.1
/uC/XTAL_P: C402.1, U402.30 (XTAL_P), Y401.3
B_3V3: C405.2, C406.2, C407.1, C408.1, C409.1, C410.1, R401.1, R402.1, R403.1, R404.1, U402.2 (VDD3P3), U402.3 (VDD3P3), U402.11 (VDD3P3_RTC), U402.17 (VDD3P3_CPU), U402.31 (VDDA), U402.32 (VDDA); also elsewhere on the board
B_5V: C413.1, D401.1 (K), U403.3 (VCC); also elsewhere on the board
B_24V: R411.2; also elsewhere on the board
B_CAN_LED: R412.1; also elsewhere on the board
B_CLOCK: U402.13 (IO7/SPI_SS); also elsewhere on the board
B_DATA: U402.12 (IO6/SPI_MOSI); also elsewhere on the board
B_GND: C401.2, C402.2, C403.1, C404.1, C405.1, C406.1, C407.2, C408.2, C409.2, C410.2, C411.2, C412.2, C413.2, J401.A1 (GND), J401.A12 (GND), J401.B1 (GND), J401.B12 (GND), J401.S1 (SHIELD), R405.2, R406.1, R410.1, SW401.2, SW402.2, U401.2 (GND), U402.33 (GND), U403.2 (GND), U403.8 (STB), Y401.2, Y401.4; also elsewhere on the board
B_ID1: U402.10 (IO5/ADC2/SPI_MISO); also elsewhere on the board
B_ID2: U402.9 (IO4/ADC1_4/SPI_SCK); also elsewhere on the board
B_ID3: U402.8 (IO3/ADC1_3); also elsewhere on the board
B_ID4: U402.5 (IO1/ADC1_1); also elsewhere on the board
B_LATCH: U402.16 (IO10); also elsewhere on the board
B_SCL: R402.2, U402.14 (IO8/BOOT); also elsewhere on the board
B_SDA: R401.2, U402.6 (IO2/BOOT/ADC1_2); also elsewhere on the board
unnamed: C411.1, U402.18 (VDD_SPI)
unnamed: D402.2 (A), D403.2 (A), R412.2
unnamed: D403.1 (K), R409.2, U403.4 (RXD)

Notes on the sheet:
RST
ADC ATTEN=0 full range 750mV 24.686V = 4096
MOD

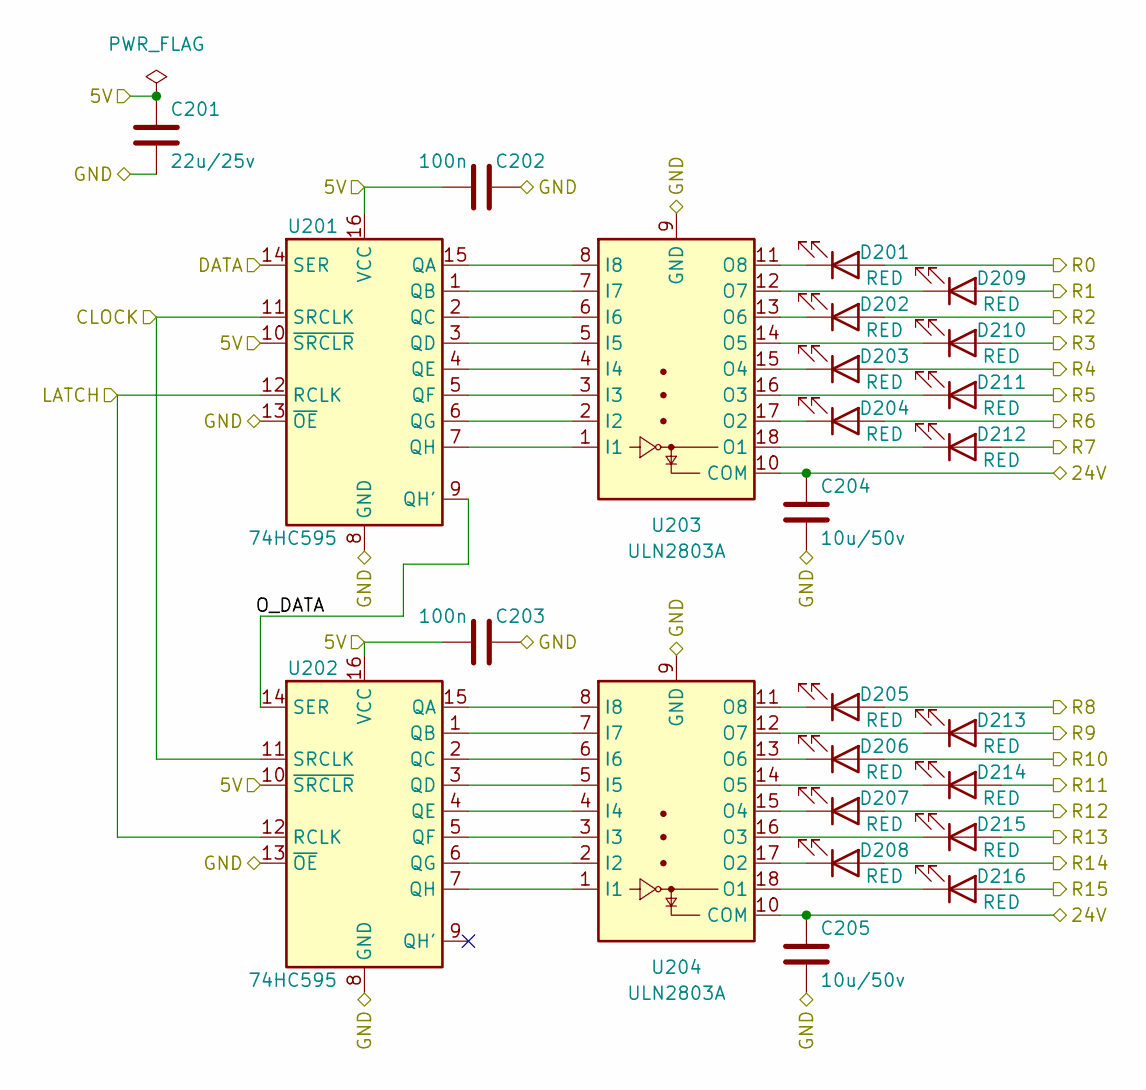
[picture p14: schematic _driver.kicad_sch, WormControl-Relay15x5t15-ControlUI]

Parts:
C201: 22u/25v; C_0805_2012Metric_Pad1.18x1.45mm_HandSolder; jlc-part-type B
C202, C203: 100n; C_0805_2012Metric_Pad1.18x1.45mm_HandSolder; jlc-part-type B
C204, C205: 10u/50v; C_0805_2012Metric_Pad1.18x1.45mm_HandSolder; jlc-part-type B
D201, D202, D203, D204, D205, D206, D207, D208, D209, D210, D211, D212, D213, D214, D215, D216: RED; LED_1206_3216Metric_ReverseMount; jlc-part-type E
U201, U202: 74HC595; SOIC-16_3.9x9.9mm_P1.27mm; jlc-part-type B
U203, U204: ULN2803A; SOIC-18W_7.5x11.6mm_P1.27mm; jlc-part-type E

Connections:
/driver/O_DATA: U201.9 (QH'), U202.14 (SER)
/driver/R0: D201.2 (A); also elsewhere on the board
/driver/R1: D209.2 (A); also elsewhere on the board
/driver/R2: D202.2 (A); also elsewhere on the board
/driver/R3: D210.2 (A); also elsewhere on the board
/driver/R4: D203.2 (A); also elsewhere on the board
/driver/R5: D211.2 (A); also elsewhere on the board
/driver/R6: D204.2 (A); also elsewhere on the board
/driver/R7: D212.2 (A); also elsewhere on the board
/driver/R8: D205.2 (A); also elsewhere on the board
/driver/R9: D213.2 (A); also elsewhere on the board
/driver/R10: D206.2 (A); also elsewhere on the board
/driver/R11: D214.2 (A); also elsewhere on the board
/driver/R12: D207.2 (A); also elsewhere on the board
/driver/R13: D215.2 (A); also elsewhere on the board
/driver/R14: D208.2 (A); also elsewhere on the board
/driver/R15: D216.2 (A); also elsewhere on the board
F_5V: C201.1, C202.1, C203.1, U201.10 (~SRCLR), U201.16 (VCC), U202.10 (~SRCLR), U202.16 (VCC); also elsewhere on the board
F_24V: C204.1, C205.1, U203.10 (COM), U204.10 (COM); also elsewhere on the board
F_CLOCK: U201.11 (SRCLK), U202.11 (SRCLK); also elsewhere on the board
F_DATA: U201.14 (SER); also elsewhere on the board
F_GND: C201.2, C202.2, C203.2, C204.2, C205.2, U201.8 (GND), U201.13 (~OE), U202.8 (GND), U202.13 (~OE), U203.9 (GND), U204.9 (GND); also elsewhere on the board
F_LATCH: U201.12 (RCLK), U202.12 (RCLK); also elsewhere on the board
unnamed: D201.1 (K), U203.11 (O8)
unnamed: D202.1 (K), U203.13 (O6)
unnamed: D203.1 (K), U203.15 (O4)
unnamed: D204.1 (K), U203.17 (O2)
unnamed: D205.1 (K), U204.11 (O8)
unnamed: D206.1 (K), U204.13 (O6)
unnamed: D207.1 (K), U204.15 (O4)
unnamed: D208.1 (K), U204.17 (O2)
unnamed: D209.1 (K), U203.12 (O7)
unnamed: D210.1 (K), U203.14 (O5)
unnamed: D211.1 (K), U203.16 (O3)
unnamed: D212.1 (K), U203.18 (O1)
unnamed: D213.1 (K), U204.12 (O7)
unnamed: D214.1 (K), U204.14 (O5)
unnamed: D215.1 (K), U204.16 (O3)
unnamed: D216.1 (K), U204.18 (O1)
unnamed: U201.1 (QB), U203.7 (I7)
unnamed: U201.2 (QC), U203.6 (I6)
unnamed: U201.3 (QD), U203.5 (I5)
unnamed: U201.4 (QE), U203.4 (I4)
unnamed: U201.5 (QF), U203.3 (I3)
unnamed: U201.6 (QG), U203.2 (I2)
unnamed: U201.7 (QH), U203.1 (I1)
unnamed: U201.15 (QA), U203.8 (I8)
unnamed: U202.1 (QB), U204.7 (I7)
unnamed: U202.2 (QC), U204.6 (I6)
unnamed: U202.3 (QD), U204.5 (I5)
unnamed: U202.4 (QE), U204.4 (I4)
unnamed: U202.5 (QF), U204.3 (I3)
unnamed: U202.6 (QG), U204.2 (I2)
unnamed: U202.7 (QH), U204.1 (I1)
unnamed: U202.15 (QA), U204.8 (I8)

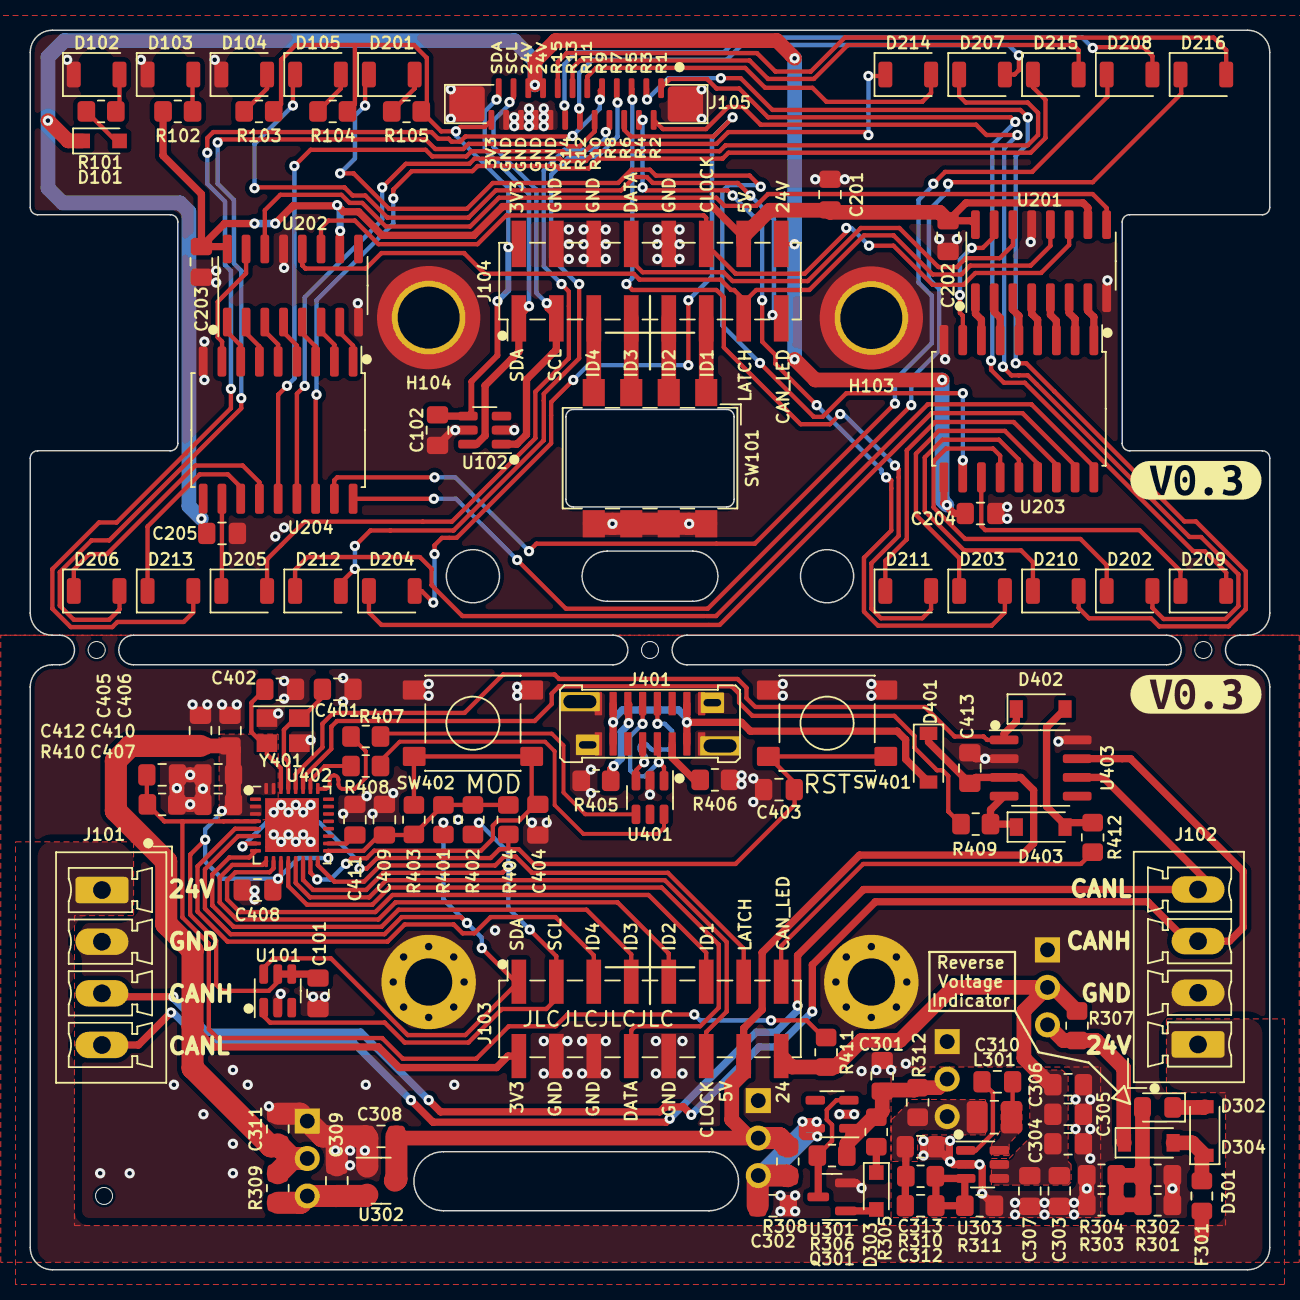
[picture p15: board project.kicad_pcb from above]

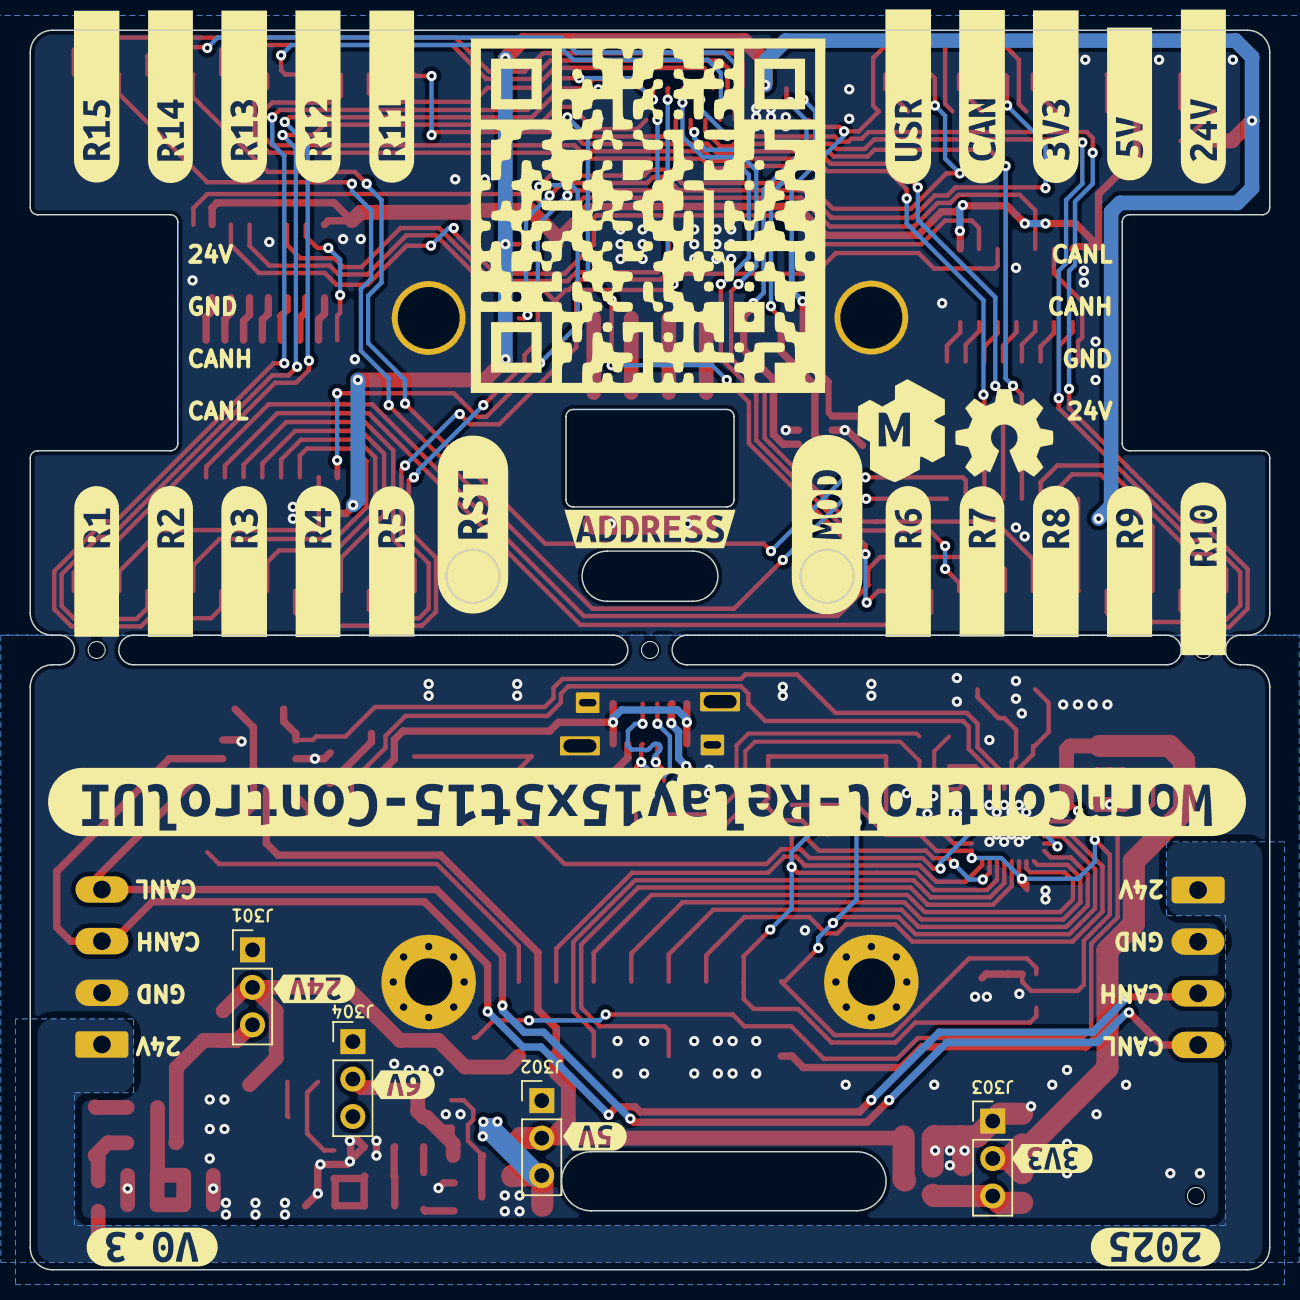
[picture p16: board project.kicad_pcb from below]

Board: 4 copper layers, 84.0 x 84.0 mm, 157 parts (36 on the bottom side), 118 nets.

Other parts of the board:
kibuzzard-68F6C7D9: G***; kibuzzard-68F6C7D9
kibuzzard-68F6C8CD: G***; kibuzzard-68F6C8CD
kibuzzard-68F6C9D1: G***; kibuzzard-68F6C9D1
kibuzzard-68F6C9D9: G***; kibuzzard-68F6C9D9
kibuzzard-68F6C81E: G***; kibuzzard-68F6C81E
kibuzzard-68F6C83B: G***; kibuzzard-68F6C83B
kibuzzard-68F6C776: G***; kibuzzard-68F6C776
kibuzzard-68F6C793: G***; kibuzzard-68F6C793
kibuzzard-67993A27: G***; kibuzzard-67993A27
kibuzzard-679934A0: G***; kibuzzard-679934A0
kibuzzard-679934B0: G***; kibuzzard-679934B0
kibuzzard-679934DC: G***; kibuzzard-679934DC
kibuzzard-679934EA: G***; kibuzzard-679934EA
kibuzzard-679935A9: G***; kibuzzard-679935A9
kibuzzard-679935B4: G***; kibuzzard-679935B4
kibuzzard-679935C1: G***; kibuzzard-679935C1
kibuzzard-6799352B: G***; kibuzzard-6799352B
kibuzzard-6799357E: G***; kibuzzard-6799357E
kibuzzard-6799359C: G***; kibuzzard-6799359C
kibuzzard-6799365E: G***; kibuzzard-6799365E
kibuzzard-67993413: G***; kibuzzard-67993413
kibuzzard-67993427: G***; kibuzzard-67993427
kibuzzard-67993436: G***; kibuzzard-67993436
kibuzzard-67993449: G***; kibuzzard-67993449
kibuzzard-67993459: G***; kibuzzard-67993459
kibuzzard-67993507: G***; kibuzzard-67993507
kibuzzard-67993514: G***; kibuzzard-67993514
kibuzzard-67993518: G***; kibuzzard-67993518
kibuzzard-67993537: G***; kibuzzard-67993537
kibuzzard-67993543: G***; kibuzzard-67993543
kibuzzard-67993570: G***; kibuzzard-67993570
kibuzzard-67993590: G***; kibuzzard-67993590

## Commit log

2024-12-16 initial draft
    [_driver.kicad_sch, _psu.kicad_sch, _uc.kicad_sch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]
2024-12-16 routing somewhat done
    [_driver.kicad_sch, project.kicad_pcb, project.kicad_sch]
2024-12-18 fixing silk and bom and generating prod/doc files
    [_bom.csv, _driver.kicad_sch, _psu.kicad_sch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]
2024-12-19 bom fixes
    [_bom.csv, _driver.kicad_sch, _psu.kicad_sch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]
2024-12-20 fixing stencil for post footprint
    [project.kicad_pcb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]
2025-01-06 adding some 3d models
    [project-B_Cu.gbr, project-B_Mask.gbr, project-B_Silkscreen.gbr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]
2025-01-06 adding buttons 3d models
    [project.kicad_pcb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]
2025-01-07 changing gerber file naming for compatibility
    [project-B_Cu.gbl, project-B_Mask.gbs, project-B_Paste.gbp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]
2025-01-07 adding screw post 3d model
    [project-B_Cu.gbl, project-B_Mask.gbs, project-B_Paste.gbp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]
2025-01-07 moving addr hole from footprint to board
    [project--NPTH_map.gbr, project--PTH_map.gbr, project-B_Cu.gbl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]
2025-01-07 adjusting hole sizes and adding qfn model
    [_uc.kicad_sch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]
2025-01-07 replacing connector and fixing models
    [_bom.csv, bom.csv, bom_lcsc.csv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]
2025-01-28 few fixes and bumping up version
    * reordering id bits
    * moving silkscreen around
    * adding hole in the center tab
    [_uc.kicad_sch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]
2025-10-21 improvements for next prototype
    * buck makes 6v now
    * using LDO for 5v with over voltage disable
    * using LDO for 3v3
    * adding zener to 24v led to stop it from glowing from 5v USB
    * added 0.2mm heigt for USB port hole
    * both buttons now 15mm height
    [_bom.csv, _driver.kicad_sch, _psu.kicad_sch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]
2025-10-31 adding threded posts to bom/pos
    [project.kicad_pcb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]
